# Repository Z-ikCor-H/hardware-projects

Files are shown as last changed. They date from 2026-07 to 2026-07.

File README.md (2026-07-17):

# Hardware Projects

个人硬件设计项目集合，包含 PCB 设计、电源模块、电路方案等。

---

## 📂 项目列表

| 项目 | 说明 | 平台 |
|---|---|---|
| [power-supply-design](power-supply-design/) | 多路输出电源模块（TPS5430 + SPX29302 + MT3608） | Altium Designer 24 |

## 🛠️ 工具

- **EDA**: Altium Designer 24
- **PCB 打样**: 适用嘉立创等常规工艺

## 📄 许可

开源硬件设计，仅供学习与参考。

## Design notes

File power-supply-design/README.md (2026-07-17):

# 电源模块设计（Power Supply Design）

基于 Altium Designer 24 的多路输出电源模块 PCB 设计项目。

## 📐 项目概述

本项目设计一个多路电源转换模块，支持三种输入方式和三路稳压输出：

| 输入 | 类型 |
|---|---|
| P1 | DC 圆口插座（3.5×1.3mm） |
| P2 | USB Type-C |

### 电源架构

```
VBAT+ ──→ [TPS5430 Buck] ──→ VCC5V (5V/3A)
                                  │
                                  └──→ [SPX29302 LDO] ──→ 3.3V/3A
                                                              │
                                                              └──→ [MT3608 Boost] ──→ +5V
```

### 主要芯片

| 芯片 | 型号 | 功能 | 封装 |
|---|---|---|---|
| U1 | TPS5430 | Buck 降压转换器，5V/3A 输出，500kHz | SOIC-8 EP (PowerPAD) |
| U2 | SPX29302 | LDO 线性稳压器，3.3V/3A | TO-263-5 |
| U3 | MT3608 | Boost 升压转换器，3.3V→5V | SOT-23-6 |
| D5 | SS54 | 肖特基二极管，5A | SMB |

### 关键网络
- `VCC5V` — TPS5430 Buck 输出
- `3.3V` — SPX29302 LDO 输出
- `+5V` — MT3608 Boost 输出
- `TYPE-C_5V` — USB-C 输入
- `GND` — 公共地

## 📁 文件结构

```
├── Power supply design.PrjPcb    # Altium 项目文件
├── dainyuan.SchDoc               # 原理图设计
├── dianyuan.PcbDoc               # PCB 设计
├── Schlib1.SchLib                # 原理图元件库
├── Power supply design.OutJob    # 输出作业配置
├── Power supply design.pdf       # 项目输出 PDF
├── buck电路元件选型计算.xlsx      # Buck 电路元件参数计算
├── 电源模块负载测试.xlsx          # 负载测试数据
├── References/                   # 芯片数据手册
│   ├── tps5430.pdf
│   ├── tps5430-中文.pdf
│   └── SPX29300.PDF
└── LICENSE                       # CERN-OHL-P v2
```

## 🛠️ 设计要点

### 过孔规则
- 默认过孔：内径 0.3mm / 外径 0.6mm（12/24mil）
- 焊环宽度：0.15mm（6mil）
- 阻焊：常规盖油，散热焊盘开窗
- 过孔间距：≥0.25mm（10mil）
- 过孔到铜皮：≥0.15mm（6mil），电源网络建议 0.2mm

### 散热设计
- TPS5430 PowerPAD 底部：9 个过孔（3×3 阵列）
- SPX29302 散热铜皮：12-16 个过孔（开窗）
- 功率焊盘与 GND 铜皮采用直接连接

## 📝 开发环境

- **EDA 工具**: Altium Designer 24
- **PCB 打样**: 适用于嘉立创等常规工艺（0.3/0.6mm 过孔为标准工艺，无额外费用）

## 📄 许可

CERN-OHL-P v2 开源硬件许可证，可自由使用、修改、分发。

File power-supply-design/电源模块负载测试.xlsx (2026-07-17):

输入 | 名称 | 空载/V | 带载4W小风扇/V/A |  | 功率/W
3.5mm12V输入 | BUCK5V | 4.98 | 4.98 | 0.12 | 0.5976
 | LDO3.3V | 3.29 | 3.29 | 0.08 | 0.2632
 | BOOST5V | 5.01 | 4.86 | 0.12 | 0.5832
type-c5V输入 | BUCK5V | 4.96 | 4.81 | 0.12 | 0.5772
 | LDO3.3V | 3.29 | 3.29 | 0.08 | 0.2632
 | BOOST5V | 5.01 | 4.86 | 0.12 | 0.5832

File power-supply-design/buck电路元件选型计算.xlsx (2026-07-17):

BUCK电路 |  |  | LDO
设计指标 |  | 计算值(统一单位) | V(OUT) | 5
输入电压V(INMAX)/V | 10.8-19.8 | 12
输入纹波电压deltaV(IN)/mV | 300 | 0.3 | R1/千欧 | 66.70967742
输出电压V(OUT)/V | 5 | 5 | R2/千欧 | 22
最大输出电压纹波deltaV(OUT)/mV | 30 | 0.03
输出电流额定值I(OUTMAX)/A | 3 | 3
工作频率f(sw)/KHz | 500 | 500000
去耦电容C(1)/uF | 100.00 | 0.0001
输入容C(IN) | 8.33 | 8.333333333e-06
ESR(C1MAX)/毫欧 | 40 | 0.04
输入纹波电压deltaV(IN)/mV | 135.00 | 0.135
输入纹波电流I(EMSMAX)=I(CIN)/mA | 1500 | 1.5
电容额定电压V(C1MAX)/V | 12.15 | 12.15
电感L(OUT)/uH | 22 | 2.2e-05
K(IND) | 0.2-0.3 | 0.3
最小电感L(MIN)/uH | 6.48 | 6.481481481e-06
电感纹波电流deltaI(L)/mA | 265.15 | 0.2651515152
电感饱和电流I(LRMS)/A | 3.00 | 3.001525335
峰值电感电流I(LPK)/A | 3.17 | 3.165719697
输出电容C(OUT)/uF | 100.00 | 0.0001
谐振频率f(LC)/KHz | 3393.19 | 3393.194788
闭环交叉频率f(CO)/KHz | 27.09 | 27091.22557
串联等效电阻ESR(MAX)/毫欧 | 58.75 | 0.05874778262
输出电压纹波V(ppMAX)/mV | 15.58 | 0.01557706357
输出电流纹波I(COUTRMS)/mA | 76.54 | 0.07654264932
电容额定电压V（C2MAX)/V | 5.01 | 5.015
R1/千欧 | 10 | 10000
R2/千欧 | 3.23 | 3231.013496

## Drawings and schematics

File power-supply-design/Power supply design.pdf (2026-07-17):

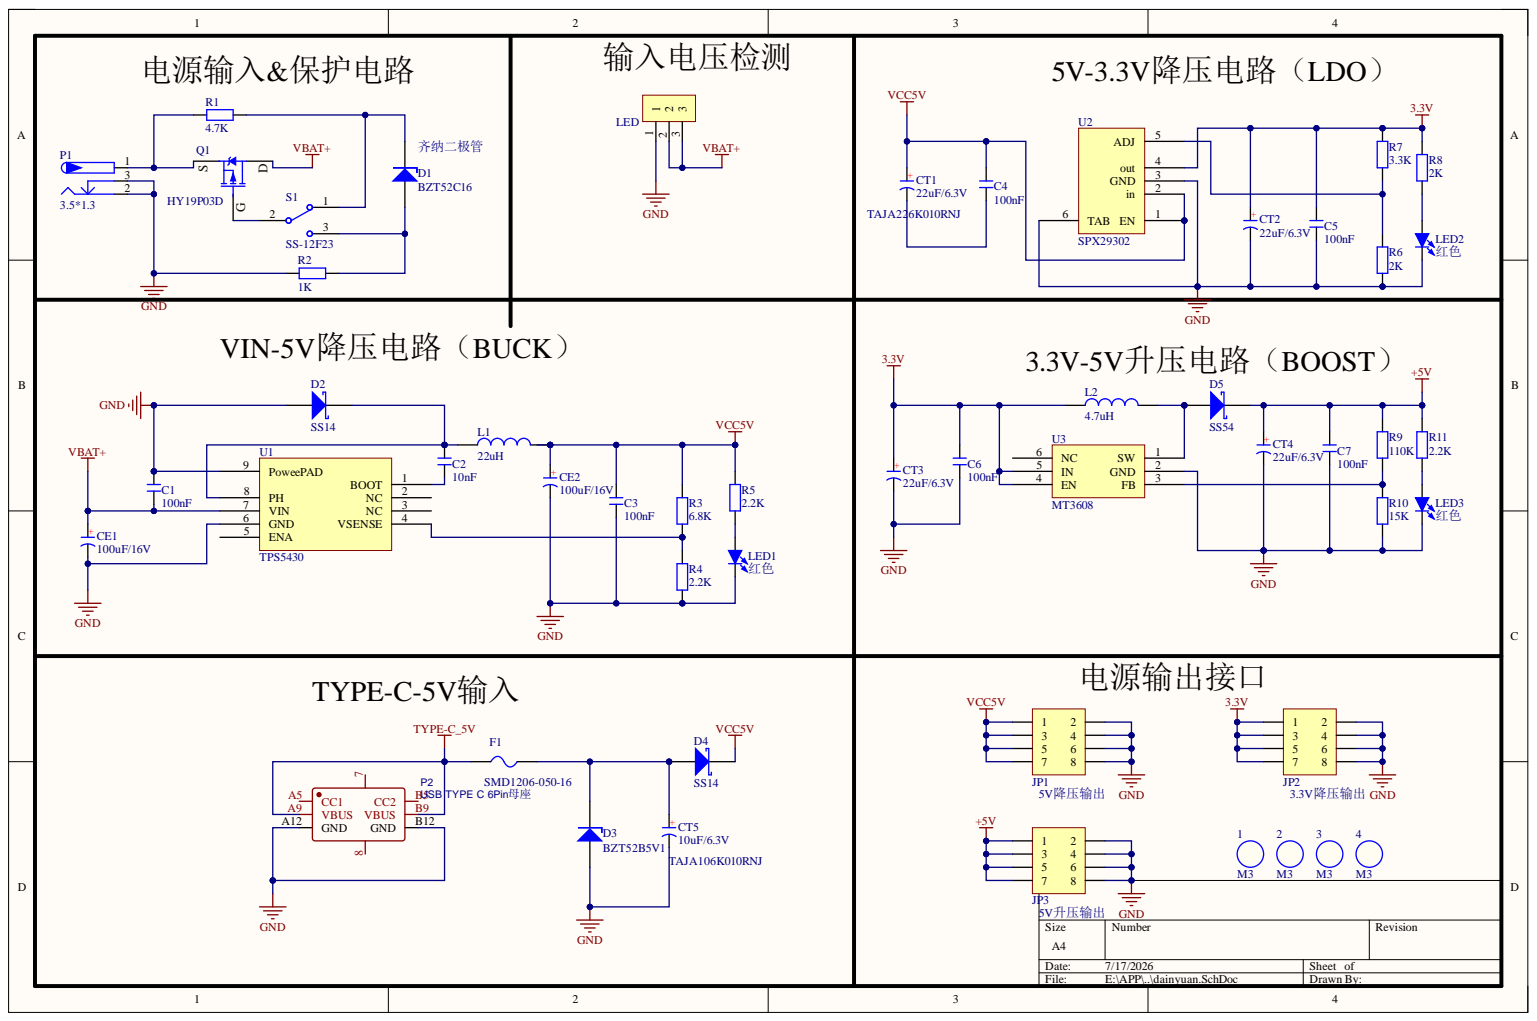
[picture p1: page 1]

VIN-5V降压电路（BUCK） D2 | GND 3.3V-5V升压电路（BOOST） 3.3V

Size A4 | Number | Revision

Date: 7/17/2026 | Sheet of
File: E:\APP\..\dainyuan.SchDoc | Drawn By:

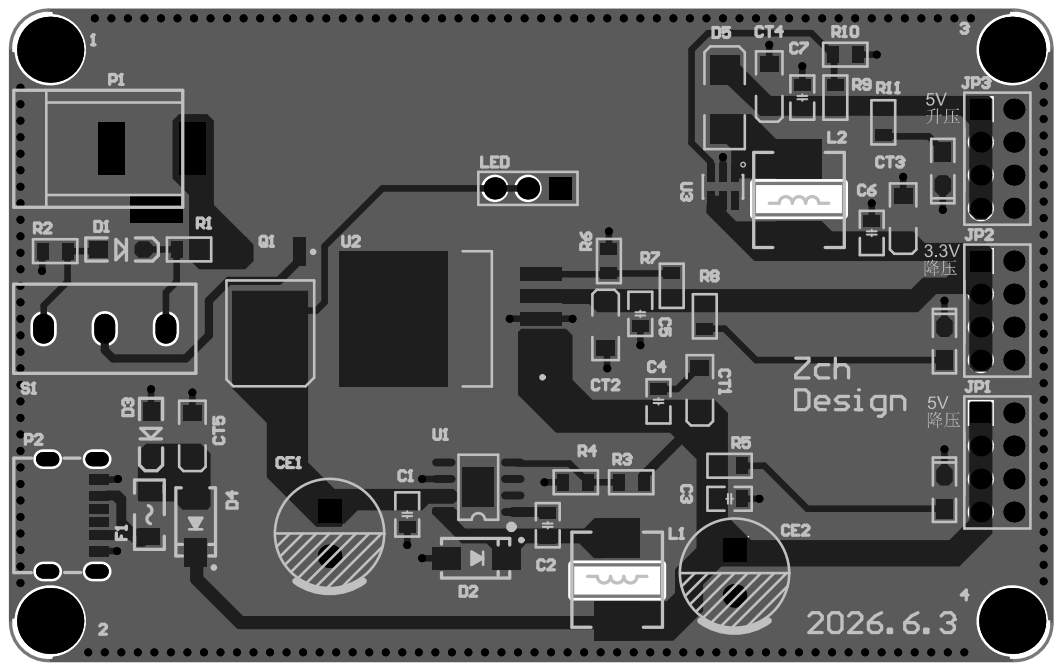
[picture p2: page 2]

Comment | Description | Designator | Footprint | LibRef | Quantity
M3 | 铜柱孔 | 1, 2, 3, 4 | M3 125X200 | M3 | 4
100nF | 贴片电容 | C1, C3, C4, C5, C6, C7 | C 0805_L | C | 6
10nF | 贴片电容 | C2 | C 0805_L | C | 1
100uF/16V | 直插电解电容 | CE1, CE2 | CAP 3.5*8*11.5 - BK | CE | 2
22uF/6.3V | 贴片钽电容 | CT1, CT2, CT3, CT4 | CD A(3216) | CT | 4
10uF/6.3V | 贴片钽电容 | CT5 | CD A(3216) | CT | 1
BZT52C16 | Zener Diode（齐 纳） | D1 | SOD-123 | 稳压二极管 | 1
SS14 | 肖特基二极管 | D2, D4 | SMA | SS14 | 2
BZT52B5V1 | Zener Diode | D3 | SOD-123 | 稳压二极管 | 1
SS54 | 肖特基二极管 | D5 | SMB | SS54 | 1
SMD1206-050-16 | 自恢复保险丝 | F1 | FU 1206 | FU | 1
Header 4X2 | 4*2P接插件 | JP1, JP2, JP3 | HDR2.54-LI-2x4P | Header 4X2 | 3
22uH | 小功率贴片电感 | L1 | L-SMD-0630 | L | 1
4.7uH | 小功率贴片电感 | L2 | L-SMD-0630 | L | 1
HDR-1X3 | 3P接插件 | LED | HDR2.54-M-LI-3P | Header 3 | 1
红色 | 贴片LED | LED1, LED2, LED3 | LED 0805R | LED-SMD | 3
3.5*1.3 | 低压电源接口 | P1 | DC-005 | P-DC | 1
USB TYPE C 6Pin母座 | | P2 | USB-C-SMD_10P-P1.00-L6.8-W8.9 | USB TYPE C 6Pin母座 | 1
HY19P03D | P沟场效应管 | Q1 | TO252 - 3 | IRF540 | 1
4.7K | 贴片电阻 | R1 | R 0805_L | R | 1
1K | 贴片电阻 | R2 | R 0805_L | R | 1
6.8K | 贴片电阻 | R3 | R 0805_L | R | 1
2.2K | 贴片电阻 | R4, R5, R11 | R 0805_L | R | 3
2K | 贴片电阻 | R6, R8 | R 0805_L | R | 2
3.3K | 贴片电阻 | R7 | R 0805_L | R | 1
110K | 贴片电阻 | R9 | R 0805_L | R | 1
15K | 贴片电阻 | R10 | R 0805_L | R | 1
SS-12F23 | 1路波动开关 | S1 | SS-12D10 | SSW-1P | 1
TPS5430 | DC可调降压 | U1 | SOIC-8_EP | TPS5430 | 1
SPX29302 | LDO线性稳压芯片 | U2 | TO263-5 | SPX29302 | 1
MT3608 | DC升压芯片 | U3 | SOT23-6 | MT3608 | 1

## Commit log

2026-07-17 init: 电源模块设计项目
    - TPS5430 Buck (5V/3A) + SPX29302 LDO (3.3V/3A) + MT3608 Boost (+5V)
    - 包含原理图、PCB、Gerber、DRC 报告、数据手册与测试数据
    [Power supply design.PrjPcb, Power supply design.xlsx, Power supply design_1.xlsx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]
2026-07-17 reorg: 将电源设计移入 power-supply-design/ 子目录
    仓库更名为 hardware-projects，支持后续添加更多项目
    [Power supply design.PrjPcb, Power supply design.xlsx, Power supply design_1.xlsx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]
2026-07-17 Delete power-supply-design/References/电源拓扑分类与应用参考.md
    此内容在笔记项目中出现
2026-07-17 chore: remove Project Outputs from tracking
    Gerber/DRC/BOM 等输出文件每次修改 PCB 均重新生成，不应存入版本控制。
    打样时单独打包发送即可。同时添加 Project Outputs for */ 到 .gitignore
    [Power supply design.xlsx, Power supply design_1.xlsx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]
2026-07-17 docs: 更新 README 文件结构，移除已清理条目
